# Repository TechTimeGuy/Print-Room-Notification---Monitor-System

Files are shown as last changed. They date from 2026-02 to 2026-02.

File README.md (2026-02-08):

# Print Room Notification / Monitor System
ESP32 + 2.8" TFT Touchscreen (Home Assistant / ESPHome)

<p align="center">
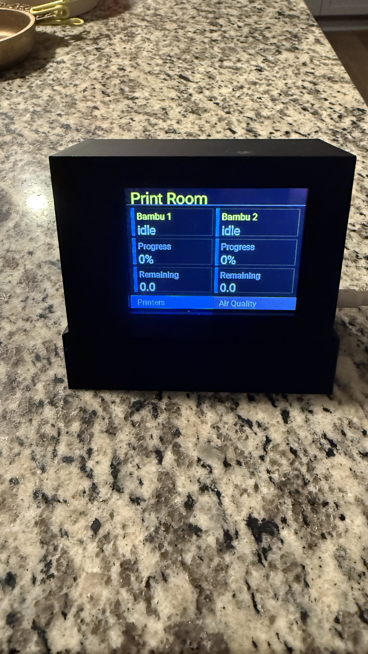
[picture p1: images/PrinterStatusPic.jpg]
  
</p>

A compact, always-on **2.8" TFT touchscreen status display** built around an **ESP32** and **Home Assistant**.
Designed for print rooms and workshops to provide real-time visibility into **air quality** and **3D printer status** without dashboards, tablets, or cloud services.

This device is display-only: all logic, thresholds, and data come directly from Home Assistant.

## Repository Structure

Print-Room-Notification---Monitor-System/
- stl/        → 3D printable enclosure files
- esphome/    → ESPHome YAML configuration
- docs/       → wiring diagrams and setup documentation
- images/     → screen layouts and project photos
- README.md
- .gitignore
- .gitattributes

## What It Displays

- Air Quality (AQI / eCO2 / TVOC)
- 3D printer status (Idle / Printing / Paused / Finished / Error)
- Print progress percentage
- Remaining print time (when available)
- Layout supports multiple printers and sensors

Originally designed around Bambu Lab printers, but compatible with **any Home Assistant printer integration**.

## Requirements

- ESP32 (required)
- 2.8" SPI TFT display (ILI9341)
- Touch controller (XPT2046)
- Home Assistant
- ESPHome

ESP8266 is **not supported** due to memory and display limitations.

## 3D Printing

Enclosure files are located in the `stl/` folder.

- Designed for standard FDM printers
- No supports required
- PLA or PETG recommended
- Desk and workbench friendly footprint

## Setup Overview

1. Print the enclosure from the `stl/` folder
2. Wire the ESP32 to the TFT display and touch controller (see `docs/`)
3. Flash the ESP32 using ESPHome and the YAML in `esphome/`
4. Confirm the device appears in Home Assistant
5. Verify sensor and printer entities are available
6. Adjust layout or displayed entities as desired

## Documentation

See the `docs/` folder for:
- Wiring references
- Display pin mapping
- ESPHome configuration notes

Screenshots and layout references can be found in the `images/` folder.

## Example Use Cases

- Print room air quality monitoring
- Live printer status and progress display
- Workshop environmental visibility
- Quiet, always-on status screen for Home Assistant

## Notes

This project was designed to be reliable, local, and distraction-free —
a purpose-built status display for environments where information needs
to be visible at a glance.

Happy building.

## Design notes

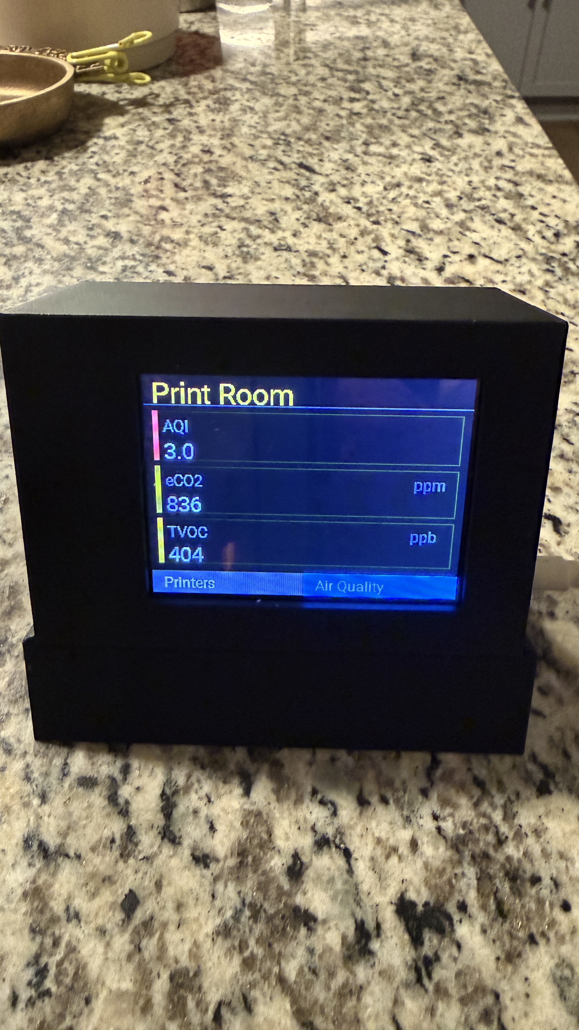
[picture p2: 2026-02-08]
images/AQI Pic.jpg

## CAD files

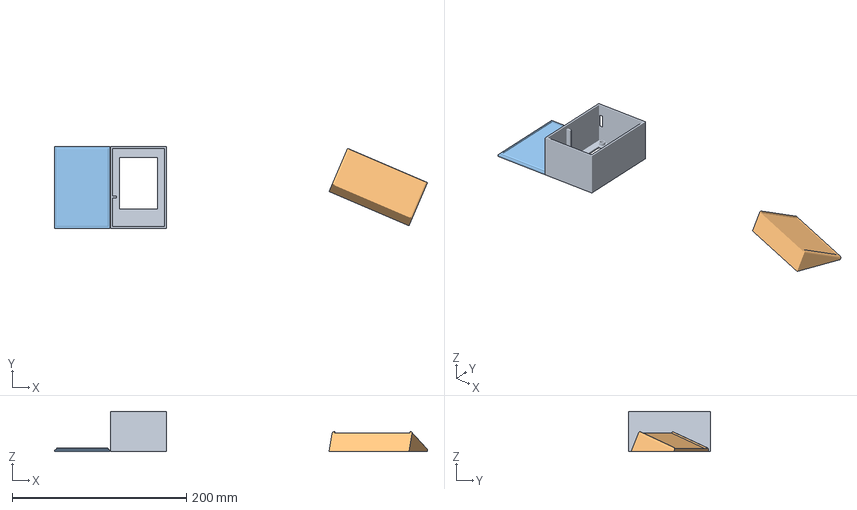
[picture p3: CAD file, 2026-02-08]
stl/Print Room Notification Center Project.3mf
428.5 x 94.0 x 46.0 mm
Angled Base.stl

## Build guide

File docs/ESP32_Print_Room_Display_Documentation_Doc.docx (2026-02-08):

# ESP32 Print Room Display Documentation

Generated: 2026-02-07

## Overview

This build uses an ESP32 driving a 2.4"/2.8" ILI9341 SPI TFT display with an XPT2046 resistive touchscreen. The UI shows a two-page dashboard: a Printers page (Bambu 1 + Bambu 2, 6 cards) and an Air Quality page (3 large cards). Touch buttons along the bottom switch pages.

## Hardware Used

Item | Notes
ESP32 DevKit (esp32dev) | ESP-IDF framework in ESPHome; static IP used for easy access.
ILI9341 SPI TFT module | Pins: VCC, GND, CS, RESET, DC, SDI(MOSI), SCK, LED, (SDO/MISO unused for TFT
XPT2046 resistive touch controller | Pins: T_CS, T_IRQ, T_CLK, T_DIN, T_DO. Shares SPI CLK/MOSI/MISO with TFT.
Dupont jumpers / Y-cables | Used to share SPI CLK and MOSI lines between TFT and touch without soldering.

).

## Power Notes (confirmed working)

VCC (module power): 5V → VCC is OK.

Backlight: 3.3V → LED (backlight) used in this build.

Ground: All grounds common (ESP32 GND « TFT GND « Touch GND).

## Wiring Table (Spreadsheet format)

Signal | TFT Pin Label | Touch Pin Label | ESP32 GPIO / Powe | r Notes
SPI CLK | SCK | T_CLK | GPIO18 | Y Cable
SPI MOSI | SDI(MOSI) | T_DIN | GPIO23 | Y Cable
SPI MISO | | | GPIO19
TFT Chip Select | CS | - | GPIO14 | TFT CS only.
TFT DC | DC | - | GPIO27
TFT Reset | RESET | - | GPIO4
Touch Chip Select | - | T_CS | GPIO25 | Touch CS only.
Touch Interrupt | - | T_IRQ | GPIO26 | Pen IRQ line.
Power | VCC | - | 5V | 5V to VCC confirmed OK.
Backlight | LED | - | 3.3V | Backlight powered from 3.3V in thi
Ground | GND | GND | GND | Common ground.

. u

s build.

Important: The TFT’s SDO(MISO) pin is not required for display-only operation. However, the touchscreen controller does

require its T_DO line to connect to the ESP32 MISO (GPIO19).

ESPHome / Display Settings

Setting | Value
ESPHome name | remote-display-screen
Framework | ESP32 + ESP-IDF
Display driver | ili9xxx (model: ili9341)
Display rotation | 270°
Display palette | 8BIT
Display update interval | 2s
Touch driver | xpt2046
Touch update interval | 50ms
Touch threshold | 400
Touch calibration | x_min=340, x_max=3760, y_min=240, y_max=3760
Touch transform | swap_xy: true, mirror_x: true, mirror_y: true
Static IP | 192.168.1.24 / 255.255.255.0, GW 192.168.1.254 ****optional or use your own

Home Assistant Entities Used ******Replace with your own Entity IDs******

Purpose | Entity ID
AQI | sensor.game_room_air_quality_s2_air_quality_index
eCO2 | sensor.game_room_air_quality_s2_eco2
TVOC | sensor.game_room_air_quality_s2_tvoc
Bambu 1 status | sensor.bambu_p1s_1_print_status
Bambu 1 progress | sensor.bambu_p1s_1_print_progress
Bambu 1 remaining | sensor.bambu_p1s_1_remaining_time
Bambu 2 status | sensor.p1s_2_print_status
Bambu 2 progress | sensor.p1s_2_print_progress
Bambu 2 remaining | sensor.p1s_2_remaining_time

Final ESPHome YAML

Full configuration:

File found in zip file attached

## Notes / Tips

- If touch feels sluggish, consider increasing the display update_interval (e.g., 3–5s) or reducing touch polling (e.g., 80–120ms).
- If touch coordinates are mirrored, adjust the transform section (swap_xy / mirror_x / mirror_y).
- If you ever move the screen rotation again, touch transform usually needs to change too.

ESP32 Print Room Display (ILI9341 + XPT2046) Documentation Page 1
